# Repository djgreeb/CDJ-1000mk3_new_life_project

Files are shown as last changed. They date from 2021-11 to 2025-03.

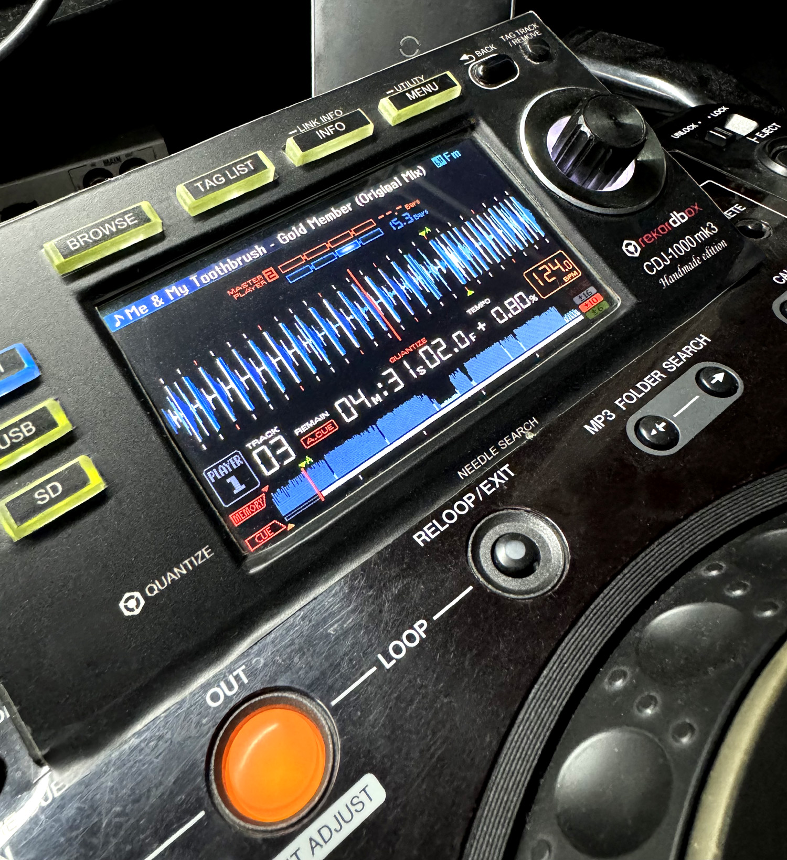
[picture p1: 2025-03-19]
v.1.17.JPG

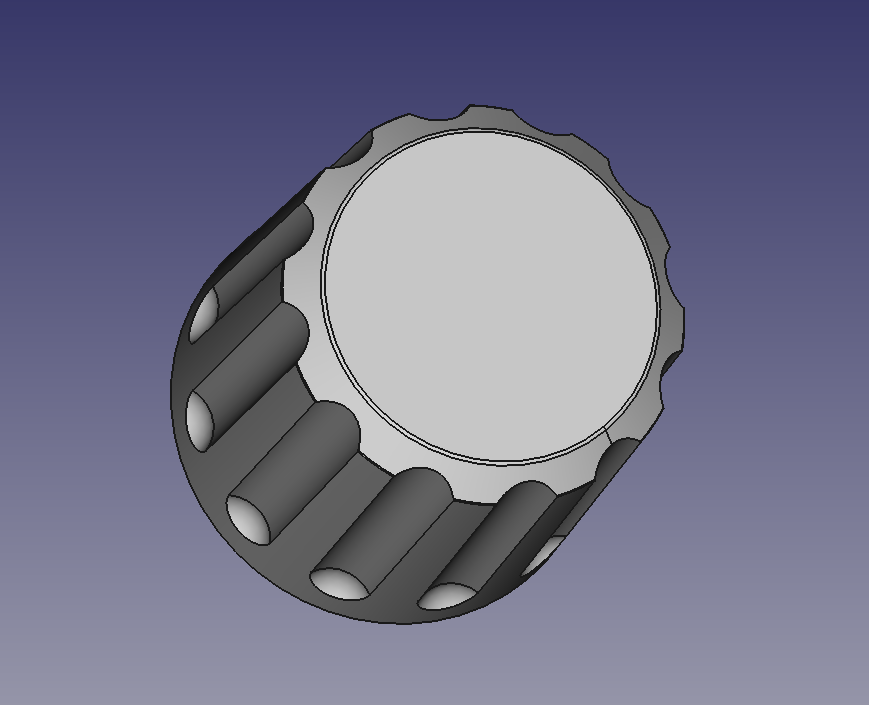
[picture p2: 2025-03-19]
Encoder knob 3D/Knob view.png

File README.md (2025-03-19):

# CDJ-1000mk3 new life

CDJ-1000mk3 new life - is a project to give new life to the Pioneer CDJ-1000mk3 dj player.

The CDJ-1000mk3 with faulty CD drive or main assy is suitable for the project. It is important that the power supply and control panel boards are in good working order.

The player is connected to the STM32F746G-DISCO board, for which firmware has been created that simulates the CDJ-2000nxs graphical interface, audio playback from micro SD cards, and playback control using the CDJ-1000mk3 control elements.

The current version of the project is developed and tested only for CDJ-1000mk3. Mk1 and MK2 are not supported, although theoretically it is possible, but requires code modification and testing with these players.

Screen with wide version of the waveform (1.17)

v 1 17

Screenshot of previous versions

scrn7

      Version history:
            
	ver. 0.61a
		- optimized browser function
		- added dark_green color in browser for text on white line cursor 
	ver. 0.62a
		- optimized DATABASE_PARSER finction
		- DATABASE_PARSER using WFORMDYNAMIC massive only 
	ver. 0.63a
		- optimized LOAD_TRACK function. Now the PCM[] massive is not used.
		- PCM[] converted in uint16_t
		- optimized audio processing for new uint16_t PCM[]. Now the calculation of 1 sample is 5us instead of 7.5us 
	ver. 0.64a
		- fixed joint in circular buffer in audio processing
		- optimized ring buffer size for increased audio processing performance
	ver. 0.65a
		- optimized audio processing (read SDRAM). Now the calculation of 1 sample is 4us 
	 	- added SD_LED blink
		- added encoder blink when loading track
	ver. 0.66a
		- added touch screen control
	ver. 0.67a
		- added basic function needle search
		- fixed function BSP_LCD_DisplayStringAt. 
		- added TRANSPARENT_MODE for text. 
		- changed method of determination the font with dynamic width (Font15P) and other fonts with static width.  
		- optimized touch controller driver
		- create audioparcer for SEEK function
	ver. 0.68a
		- added QSPI flash support
		- added animation startup logo
	ver. 0.69a
		- added REKORDBOX logo on startup
		- added tag list 
		- added internal function for RedrawWaveforms process 
	ver. 0.70a
		- added INFO mode in BROWSER and TAG LIST menu
		- added internal functions for optimize code
	ver. 0.71a
		- improved the functionality of the TAG LIST menu
	ver. 0.72a
		- added symbol red check mark for TAG LIST
		- improved the functionality of the TAG LIST (added TAG TRACK/REMOVE button)
		- bugs fixes internal functions browser and tag list
		- bugs fixes NAVIGATOR function
		- added loading track from TAG LIST
	ver. 0.73a
		- added UTILITY window
		- added long press MENU button for entering to UTILITY
		- fixed check WAV header
		-	optimized process add/delete tracks in TAG LIST
	ver. 0.74a
		- added SPI transfer for CDJ-1000mk3 panel
	ver. 0.75a
		- added reading cues and memory pionts from ANLZXXXX.DAT
		- fixed bug SPI DMA (see note*) 
	ver. 0.76a
		- added PLAY, TEMPO, TEMPO RESET, JOG MODE buttons
		- added pitch slider 4 ranges
		- added calculation tempo and bpm after pitch change
	ver. 0.77a
		- added PLAY blink led, CUE led
		- improved jog vinyl mode (inertial process)
		- added TRACK SEARCH buttons
		- improved ShowTempo function
		- added TIME MODE button, REMAIN MODE
		- added CDJ JOG MODE work
		- optimized pitch bend coeficients aka CDJ-1000mk3
		- optimized VINYL MODE precision jog step
	ver. 0.78a
		- improved static scroll UI
		- added BEATGRID massive
		- shift up 1px static information, static waveform 
		- beatgrid support
		- improved Phase Meter
	ver. 0.79a
		- improved BPM calculating after pitch change
		- added BPMGRID for tracks with variable BPM 
	ver. 0.80a
		- added Font13D for phase bars
		- added slip mode marker on jog display
		- added master player ICON
		- added slip mode red button and slip mode jog illumination
		- fixed bug spin jog at maximum speed (variable overflow)
		- added first SLIP MODE functions with audio processing
		- added animation icon and gradient for phase bars
		- improved jog pitch bend in reverse mode
		- improved jog in slip mode
	ver. 0.81a
		- added CUE blink
		- improved time mode button code
		- added VINYL RELEASE/START and TOUCH/BREAKE mode 
		- optimized SPI-DMA transfer process
		- optimized potenciometer's curve for VINYL RELEASE/START and TOUCH/BREAKE mode
	ver. 0.82a
		- added track nubmer and status (playing or played) in INFO mode
		- added filling buffer step sequencer for optimize time gaps
		- fixed filling buffer step sequencer algoritm
	ver. 0.83a
		- improved the work of the function of static and dynamic waveforms
		- added "remain/foward time style" for progress bar
	ver. 0.84b
		- added blink progress bar when the remaining time is less than 30sec
		- fixed DrawMinuteMarkers function
		- improved performance static and dynamic waveforms (added ForceDrawVLine function)
		- added checking device UID 
		- fixed fatal error when deleting a track from an empty tag list
		- the first addition of a function CUE audio
	ver. 0.85b
		- added CUE button process
		- improved CUE audio process
		- optimized pitch bend coefficients
		- added loading of Hot Cues and Memory Cues attributes
	ver. 0.86b
		- added MEMORY CUE calling
		- bugs fixes calling CUEs when jog in CDJ mode
		- added CUE, MEMORY CUE and HOT CUE triangles on dynamic waveform
	ver. 0.90b
		- database parser DeviceSQL updated based on document: "Rekordbox Export Structure Analysis" James Elliott Deep Symmetry, LLC
		- change colorystic dynamic waveform (lower white point)
		- change long touch timer for MENU button
		- added bpm to INFO menu
		- added colored rating to INFO menu
		- added KEY to INFO menu
		- added duration to INFO menu
		- maximum tracks in database - 512 (not enough memory)
		- maximum playlists in database - 20 (not enough memory)
		- supported only latin encoding in track names and tags
		- added encoder signal filter
		- show KEY on waveform fisplay
		- added pages in the browser with animation: playlists, tracks, SD card information
		- browser animation bug fixed
		- resized cue marker on dynamic waveform
		- change logic INFO button
		- fixed database parser
		- fixed text line overflow error
		- added REALTIME CUE (set, when track playing) 			
		- added AUTO CUE to the first bit of the bitgrid
		- added full UID chip in HEX in utility			
		- fixed TAG LIST exiting borders when deleting tracks
	ver. 0.97b
		- improved browser menu
		- add flash disk name and date (at the root of the browser)
		- fixed floating pitch tempo values
		- improved slip mode on CUE
		- fixed the work of jog with a hot CUE
		- improved mechanical imitation of jog
		- changed color and style gradient bar
		- changed color dynamic waveform
		- optimized dynamic waveform work
		- added QUANTIZE for CUE and LOOP
		- exclude noise at the end of the track
		- added CRC control for SPI Rx package
		- fixed start phase detection BEATGRID
		- added LOOP MODE (beta)
		- optimized time display function to improve performance	
	ver. 1.03
		- changed function control for SPI Rx package
		- in UTILITY it is now possible to change parameters and save to internal memory
		- added load lock
		- added AUTO CUE LEVEL with MEMORY, FIRST BEAT MODE and analog tresholds (-36dB, -42dB and other)
		- added TIME MODE DEFAULT 
		- added TEMPO RANGE DEFAULT 
		- SLIP REVERSE MODE for REVERSE SWITCH
		- added ability to select RGB or BLUE waveforms
		- added LCD brightness
		- added jog indicator when the track ends 
		- added jog brightness
		- added BPM color
		- added audio output level
		- for use JOG PWM output pin CN4-7 for it to work. see schematic STM32F746 Discovery
		- for LCD PWM to work, remove R85 and install 
			it between U10-7 and GND. Remove R81 and R66. Connect together the U10-7 and RMII_CRS_DV, 
			at the point where R66 was.) see schematic STM32F746 Discovery
	ver. 1.05
		- added dynamic waveform color map from original dump cdj-2000nxs
	ver. 1.07
		- fixed rekordbox parser from parser version 0.39 SLDZ project
	ver. 1.11 
		- SDRAM initialization has been removed, which speeds up loading
		- the code is split into separate files
		- increased delay before starting SPI DMA to start transactions between STM and Pioneer panel mpu
		- modify HAL_SAI_Transmit_IT and SAI_FillFifo and HAL_SAI_IRQHandler function
	ver. 1.13 
		- changed interpolators coefficients (optimal 32x, 4-point, 3rd-order)
	ver. 1.15 
		- optimized audio prc (removed unnecessary variable translation operation before sending to SAI)
		- added variable audio TRIM depending on playback speed
		- added an algorithm for smooth changes in the TRIM variable to prevent clicks in the sound when there is a sudden change
	ver. 1.17
		- the dynamic waveform is now 480px wide and has HOT CUEs lettering

Source code 1.03:

https:drive.google.com/file/d/1VFx4JItAnkkie4v-_Njo-SxVj8lTepl5/view?usp=sharing

https:drive.google.com/open?id=18gmD5JTporbCdqWj66FL6tRKBdp1W8vY

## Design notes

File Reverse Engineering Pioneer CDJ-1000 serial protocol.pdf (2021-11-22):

### Pioneer CDJ-1000mk3 Service Manual:

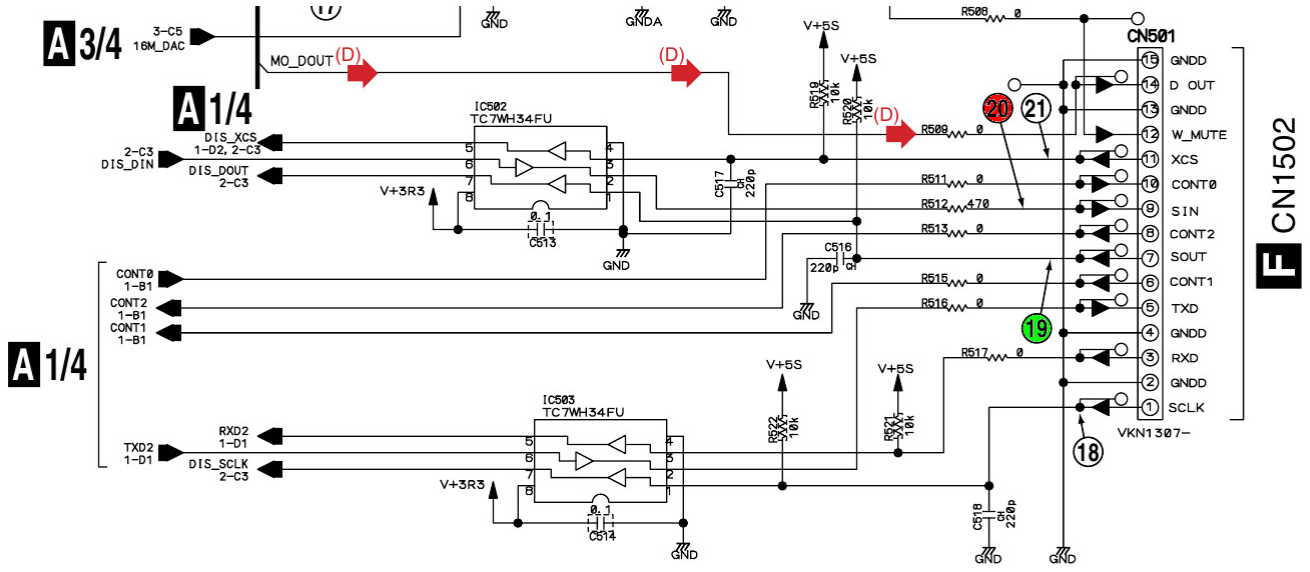
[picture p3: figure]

### 19 - Display Board => Main Assy 20 - : Main Assy => Display Board

### Data: Main Assy => Display Board @ Pioneer CDJ-1000mk3

### Example: MSB b7…..b0 LSB

/ | 0byte | 1byte | 2byte | 3byte | 4byte | 5byte | 6byte | 7byte | 8byte | 9byte | 10byte | 11byte | 12byte | 13byte | 14byte | 15byte | 16byte | 17byte | 18byte | 19byte | 20byte | 21byte | 22byte | 23byte | 24byte | 25byte | 26byte
0 package | 0 | WFM | WFM | WFM | WFM | WFM | WFM | WFM | WFM | WFM | WFM | WFM | WFM | WFM | WFM | WFM | WFM | WFM | WFM | WFM | WFM | WFM | WFM | WFM | WFM | POS | CRC
1 package | 24 | WFM | WFM | WFM | WFM | WFM | WFM | WFM | WFM | WFM | WFM | WFM | WFM | WFM | WFM | WFM | WFM | WFM | WFM | WFM | WFM | WFM | WFM | WFM | WFM | POS | CRC
2 package | 48 | WFM | WFM | WFM | WFM | WFM | WFM | WFM | WFM | WFM | WFM | WFM | WFM | WFM | WFM | WFM | WFM | WFM | WFM | WFM | WFM | WFM | WFM | WFM | WFM | POS | CRC
3 package | 72 | WFM | WFM | WFM | WFM | WFM | WFM | WFM | WFM | WFM | WFM | WFM | WFM | WFM | WFM | WFM | WFM | WFM | WFM | WFM | WFM | WFM | WFM | WFM | WFM | POS | CRC
4 package | 96 | WFM | WFM | WFM | WFM | BAR | BAR | BAR | BAR | BAR | BAR | BAR | BAR | BAR | BAR | BAR | BAR | BAR | 00000000 | BAR | BAR | BAR | BAR | BAR | BAR | POS | CRC
5 package | 120 | BAR | BAR | BAR | BAR | BAR | BAR | BAR | BAR | BAR | BAR | BAR | BAR | BAR | BAR | BAR | BAR | BAR | BAR | BAR | BAR | BAR | 00000000 | 00000000 | 00000000 | POS | CRC
6 package | 144 | ALL | ALL | ALL | AA000000 | ALL | ALL | ALL | ALL | ALL | AA000000 | ALL | ALL | ALL | ALL | ALL | ALL | ALL | ALL | A10001A1 | 00000000 | 00000000 | 00000000 | 00000000 | 00000000 | POS | CRC
7 package | 168 | ALL | ALL | ALL | ALL | ALL | ALL | ALL | ALL | AAA00001 | 1AA10000 | ALL | AA000000 | 00000000 | 00000000 | 00000000 | 00000000 | ALL | 0AAAAAAAAAAAA000 | | ALL | ALL | 00000000 | 0AAAA000 | 00000000 | POS | CRC

[all packages][0 byte] – number of package
[all packages][25 byte] = POS 1…135 – jog display position cursor 138 = eject animation 137 = load in animation 136 = fill circle on display
[all packages][26 byte] – CRC = (1byte + 2byte +…+25byte)%256
BAR - display TIME progress bar (start: [4package][19 byte] end: [5package][8 byte] first bit: b0)
BAR - display CUE progress bar (start: [5package][9 byte] end: [5package][21 byte] first bit: b0)
BAR - display MEMORY progress bar (start: [4package][5 byte] end: [4package][17 byte] first bit: b0) WFM – display WAVEFORM DATA (start: [0package][1 byte] end: [4package][4 byte] first bit: b0)

[6package][1 byte] = xA Track Number (119 = ‘0’ 93 = ‘5’ 18 = ‘1’)
[6package][2 byte] = Ax Track Number or xA Folder Number
[6package][3 byte] = Ax Folder Number (119 = ‘0’ 93 = ‘5’ 18 = ‘1’)

[6package][4 byte][bit6] = ‘FLD’ on display
[6package][4 byte][bit7] = ‘TRACK’ on display

[6package][5 byte] [bit0] = [1] number of track on display table [6package][5 byte] [bit1] = [2] number of track on display table [6package][5 byte] [bit2] = [3] number of track on display table [6package][5 byte] [bit3] = [4] number of track on display table [6package][5 byte] [bit4] = [1] track enable CUE in memory on display table

[6package][5 byte] [bit5] = [2] track enable CUE in memory on display table [6package][5 byte] [bit6] = [3] track enable CUE in memory on display table [6package][5 byte] [bit7] = [4] track enable CUE in memory on display table

[6package][6 byte] [bit0] = [5] number of track on display table [6package][6 byte] [bit1] = [6] number of track on display table [6package][6 byte] [bit2] = [7] number of track on display table [6package][6 byte] [bit3] = [8] number of track on display table [6package][6 byte] [bit4] = [5] track enable CUE in memory on display table [6package][6 byte] [bit5] = [6] track enable CUE in memory on display table [6package][6 byte] [bit6] = [7] track enable CUE in memory on display table [6package][6 byte] [bit7] = [8] track enable CUE in memory on display table

[6package][7 byte] [bit0] = [13] track enable CUE in memory on display table [6package][7 byte] [bit1] = [14] track enable CUE in memory on display table [6package][7 byte] [bit2] = [15] track enable CUE in memory on display table [6package][7 byte] [bit3] = [16] track enable CUE in memory on display table [6package][7 byte] [bit4] = [13] number of track on display table [6package][7 byte] [bit5] = [14] number of track on display table [6package][7 byte] [bit6] = [15] number of track on display table [6package][7 byte] [bit7] = [16] number of track on display table

[6package][8 byte] [bit0] = [9] number of track on display table [6package][8 byte] [bit1] = [10] number of track on display table [6package][8 byte] [bit2] = [11] number of track on display table [6package][8 byte] [bit3] = [12] number of track on display table [6package][8 byte] [bit4] = [9] track enable CUE in memory on display table [6package][8 byte] [bit5] = [10] track enable CUE in memory on display table [6package][8 byte] [bit6] = [11] track enable CUE in memory on display table [6package][8 byte] [bit7] = [12] track enable CUE in memory on display table

[6package][9 byte] [bit0] = [17] track enable CUE in memory on display table [6package][9 byte] [bit1] = [18] track enable CUE in memory on display table [6package][9 byte] [bit2] = [19] track enable CUE in memory on display table [6package][9 byte] [bit3] = [20] track enable CUE in memory on display table [6package][9 byte] [bit4] = [17] number of track on display table [6package][9 byte] [bit5] = [18] number of track on display table [6package][9 byte] [bit6] = [19] number of track on display table [6package][9 byte] [bit7] = [20] number of track on display table

[6package][10 byte] [bit6] =CUE> on display
[6package][10 byte] [bit7] =MEMORY> on display

[6package][11 byte] = xA Time: SEC (119 = ‘0’ 93 = ‘5’ 18 = ‘1’) [6package][12 byte] = Ax Time: SEC (119 = ‘0’ 93 = ‘5’ 18 = ‘1’) [6package][13 byte] = xxA Time: MIN (119 = ‘0’ 93 = ‘5’ 18 = ‘1’)
[6package][14 byte] = xAx Time: MIN (119 = ‘0’ 93 = ‘5’ 18 = ‘1’)
[6package][15 byte] = Axx Time: MIN (119 = ‘0’ 93 = ‘5’ 18 = ‘1’)
[6package][16 byte] = xxA ALL TRACKS (119 = ‘0’ 93 = ‘5’ 18 = ‘1’) when tracks>99 only [6package][17 byte] = xA ALL TRACKS (119 = ‘0’ 93 = ‘5’ 18 = ‘1’)
[6package][18 byte] = Ax ALL TRACKS (119 = ‘0’ 93 = ‘5’ 18 = ‘1’)

[6package][19 byte][bit1] = REMAIN on display
[6package][19 byte][bit7] = A.CUE on display

[7package][1 byte] = xxA tempo (119 = ‘0’ 93 = ‘5’)
[7package][2 byte] = xAx tempo (119 = ‘0’ 93 = ‘5’ 18 = ‘1’) [7package][3 byte] = Axx tempo (119 = ‘0’ 93 = ‘5’ 18 = ‘1’) [7package][4 byte] = xA Time: Frame (119 = ‘0’ 93 = ‘5’ 18 = ‘1’) [7package][5 byte] = Ax Time: Frame (119 = ‘0’ 93 = ‘5’ 18 = ‘1’) [7package][6 byte] = xxA BPM (119 = ‘0’ 93 = ‘5’ 18 = ‘1’) [7package][7 byte] = xAx BPM (119 = ‘0’ 93 = ‘5’ 18 = ‘1’)

[7package][8 byte] = Axx BPM (119 = ‘0’ 93 = ‘5’ 18 = ‘1’)

[7package][9 byte][]
[7package][9 byte]: x11xxxxx (‘+’ on tempo) x10xxxxx (‘-’ on tempo)
x00xxxxx (‘ ’ on tempo)
[7package][9 byte][bit7] = Ax.xx% = ‘1’ of pitch display

[7package][10 byte] [bit5] = xx.x% = ‘.’ dot of pitch display [7package][10 byte] [bit6] = x.xx% = ‘.’ dot of pitch display

[7package][11 byte] | : | 10010000 +-6% on display 10100000 +-10% on display
11000000 | +-16% on display
10000000 | WIDE on display

[7package][12 byte][bit6] = 1 when WIDE Pitch Enable [7package][12 byte][bit7] – MT on display or red diode on button

[7package][17 byte][bit0] = PLAY LED
[7package][17 byte][bit1] = CUE LED
[7package][17 byte][bit2] = LOOP IN LED
[7package][17 byte][bit3] = LOOP OUT LED [7package][17 byte][bit4] = RELOOP EXIT LED [7package][17 byte][bit5] = RED DIODE REVERSE [7package][17 byte][bit6] = RED DIODE HOT CUE A [7package][17 byte][bit7] = GREEN DIODE HOT CUE A

[7package][18 byte][bit0] = ORANGE DIODE HOT CUE A [7package][18 byte][bit1] = RED DIODE HOT CUE B [7package][18 byte][bit2] = GREEN DIODE HOT CUE B [7package][18 byte][bit3] = ORANGE DIODE HOT CUE B [7package][18 byte][bit4] = RED DIODE HOT CUE C [7package][18 byte][bit5] = GREEN DIODE HOT CUE C [7package][18 byte][bit6] = ORANGE DIODE HOT CUE C [7package][18 byte][bit7] = 0

[7package][19 byte][bit3] =MT red diode on button [7package][19 byte][bit4] = tempo reset green diode [7package][19 byte][bit5] = Vinyl blue diode
[7package][19 byte][bit6] = CDJ green diode
[7package][19 byte][bit7] = SD card green diode
[7package][20 byte] | : | 00001000 +-6% on display 00011000 +-10% on display
00111000 | +-16% on display
01111000 | WIDE on display

[7package][21 byte] CPOS 1…85 – jog display position CUE cursor 0 = without cue on jog display

[7package][23 byte][bit3] [bit4] = ”Vinyl ON” on VFD lamp
[7package][23 byte][bit5] = circle “touch enable” on VFD lamp
[7package][23 byte][bit6] = circle “memory empty” on VFD lamp

### 7-segment code:

119 = ‘0’
18 = ‘1’
107 = ‘2’
91 = ‘3’
30 = ‘4’

93 = ‘5’
125 = ‘6’
19 = ‘7’
127 = ‘8’
95= ‘9’

### Data: Display Board => Main Assy @ Pioneer CDJ-1000mk3

/ | 0byte | 1byte | 2byte | 3byte | 4byte | 5byte | 6byte | 7byte | 8byte | 9byte | 10byte | 11byte | 12byte | 13byte | 14byte | 15byte | 16byte | 17byte | 18byte | 19byte | 20byte | 21byte | 22byte | 23byte | 24byte | 25byte | 26byte
0-7 packages | 1 | 16 | ADC T/B | ADC R/S | ADC P | ADC P | ADCT | ADCT | PLS CNT | PLS CNT | JOG SPD | JOG SPD | JOG STS | 00000000 | ALL | 00000000 | ALL | ALL | ALL | CRC | 241 | 100 | 118 | 00000000 | 00000000 | 00000000 | 00000000
[0-7packages][2 byte] = ADC data TOUCH/BRAKE | 0…255 8 bits resolution
[0-7packages][3 byte] = ADC data RELEASE/START | 0…255 8 bits resolution
[0-7packages][4 byte] = ADC Pitch MSB [AAAAAAAA] | 0…16383 14 bits resolution
[0-7packages][5 byte] = ADC Pitch LSB [AAAAAA00]
[0-7packages][6 byte] = ADC Pitch Center Potentiometer MSB [AAAAAAAA] | 0…16383 14 bits resolution
[0-7packages][7 byte] = ADC Pitch Center Potentiometer LSB [AAAAAA00]
[0-7packages][8 byte] = Jog Pulse Counter MSB 0…65535 16 bits resolution (3600 pulses per 1 round) [0-7packages][9 byte] = Jog Pulse Counter LSB
[0-7packages][10 byte] = Jog Speed MSB 0…65535 16 bits resolution (when jog stopped speed = 65535) [0-7packages][11 byte] = Jog Speed LSB

[0-7packages][12 byte][bit0] = Eject Lock switch: 1 = unlock / 0 = lock
[0-7packages][12 byte][bit1] = Direction switch: 1 = forward / 0 = reverse
[0-7packages][12 byte][bit2] = 0
[0-7packages][12 byte][bit3] = 0
[0-7packages][12 byte][bit4] = jog touch enable
[0-7packages][12 byte][bit5] = jog touch enable
[0-7packages][12 byte][bit6] – 1 = jog forward rotation / 0 = jog reverse rotation [0-7packages][12 byte][bit7] = jog rotation detect

[0-7packages][14 byte][bit0] = PLAY button
[0-7packages][14 byte][bit1] = CUE button
[0-7packages][14 byte][bit2] = Loop IN button [0-7packages][14 byte][bit3] = Loop OUT button [0-7packages][14 byte][bit4] = Reloop/Exit button [0-7packages][14 byte][bit5] = Hot Cue A button [0-7packages][14 byte][bit6] = Hot Cue B button [0-7packages][14 byte][bit7] = Hot Cue C button

[0-7packages][16 byte][bit0] = REC MODE [0-7packages][16 byte][bit1] = << Track search [0-7packages][16 byte][bit2] = Track search >> [0-7packages][16 byte][bit3] = << Search [0-7packages][16 byte][bit4] = Search >> [0-7packages][16 byte][bit5] = 0
[0-7packages][16 byte][bit6] = 0
[0-7packages][16 byte][bit7] = 0

[0-7packages][17 byte][bit0] = < MP3 FOLDER SEARCH [0-7packages][17 byte][bit1] = MP3 FOLDER SEARCH > [0-7packages][17 byte][bit2] = JOG MODE button [0-7packages][17 byte][bit3] = TEMPO button [0-7packages][17 byte][bit4] = MASTER TEMPO button [0-7packages][17 byte][bit5] = TEMPO RESET button [0-7packages][17 byte][bit6] = 0
[0-7packages][17 byte][bit7] = 0

[0-7packages][18 byte][bit0] = CALL > [0-7packages][18 byte][bit1] = < CALL

[0-7packages][18 byte][bit2] = MEMORY button [0-7packages][18 byte][bit3] = DELETE
[0-7packages][18 byte][bit4] = EJECT button
[0-7packages][18 byte][bit5] = TIME MODE/AUTO CUE button [0-7packages][18 byte][bit6] = TEXT MODE button [0-7packages][18 byte][bit7] = 0

[0-7packages][19 byte] - CRC

Author: Anatsko Andrei

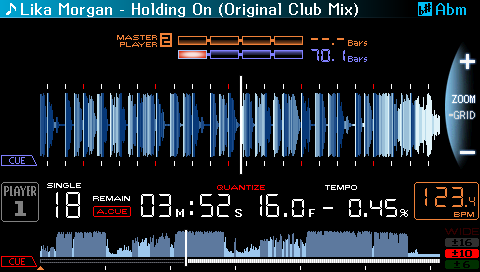
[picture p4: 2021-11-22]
scrn7.bmp

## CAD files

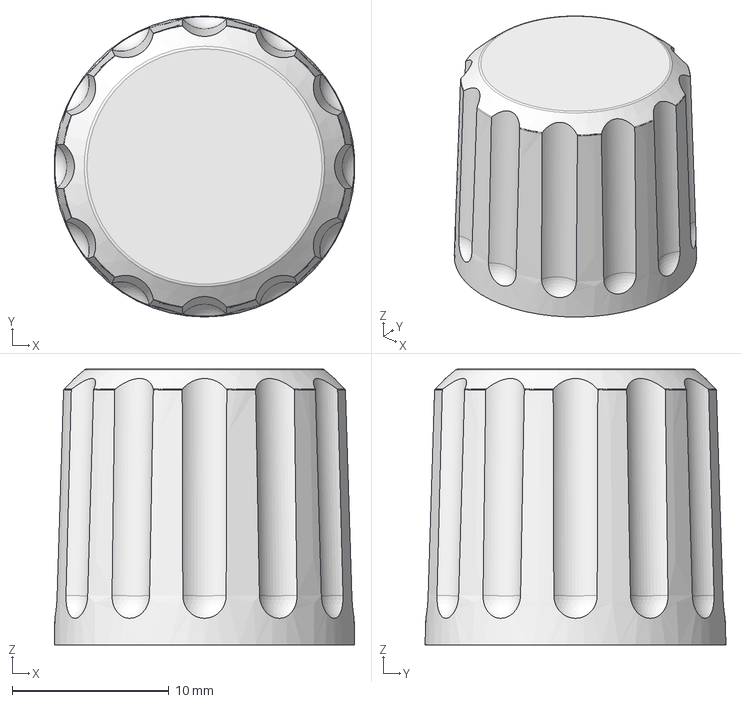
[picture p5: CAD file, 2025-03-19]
Encoder knob 3D/knob_edit24.FCStd
19.2 x 19.2 x 17.6 mm

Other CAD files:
Encoder knob 3D/knob_edit24.stl

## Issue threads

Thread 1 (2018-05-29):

STM32F746 Stuck on loading of logo

ArthurEschner, 2018-05-29:
Followed the install instructions, but the microcontrollers takes forever to load the logo, then it shows the version & progress bar rolls across the display and then it is stuck. It just doesn't do anything after that. Version 85 is the one im referring to. However V86 doesn't even complete loading the logo. Is there anything / settings that I have overlooked in the STUtily app? Any help will be really appreciated.

djgreeb, 2018-05-29:
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

The reason is found. The normal operation of the STM board is prevented by the signals ULPI_1 and ULPI_13. Cut the paths as shown in the picture in my manual (page 12).  I wrote the manual after cutting these paths, so I did not take into consideration that they would interfere with the loading in the new STM boards. Those who first cut the paths, and then downloaded the firmware, did not encounter this problem. Good luck!

ArthurEschner, 2018-05-29:
Totally sorted the issue out. Thank you so much!!

ArthurEschner, 2018-05-31:
Damn, I think I killed my Discovery board!!
It was working perfectly, but after I connected it to the cdj, the screen turned on green (still shows rekordbox though). It's almost like it's missing one layer. Occasionally the screen will display things normally again, but for the most part it's just green. Pc still detects it, but the display seems very dodgy :(  I have ordered another 2 discovery boards & will work on them with extra care next time. If you have any ideas what might be causing my screen issue, I'd appreciate your input. Thanks for your guidance. Regards.

djgreeb, 2018-06-01:
oh, I sympathize with your bad news. Download the demonstration firmware from the STmicroelectronics.com website and flash your STM32F746G board using the STLink utility, check if everything is working on your board (display, touchscreen, audio codec). If you do not find the demonstration firmware, write to me, I will send it to you.
What exactly did you already connect to the CDJ? What signals?
In your CDJ were some kind of defect before that?
Before connecting a new STM32F746G board, check that the CDJ outputs the required voltage (5V and 12V for vled). Did you install the 74HC245 chip? Make sure that this chip receives power from the board STM32F746G (3,3V) not 5V! it is important!

If in CDJ you have already deleted the original display, then it is necessary to apply a 5V 36ohm resistor.

Follow all the steps in the instructions sequentially, after each step, check if you have done everything correctly, only then go to the next step. All connections are made when your board and your CDJ are disconnected from the power.
Sorry, my English is bad, I use a translator.
Good luck to you!

djgreeb, 2018-06-01:
Problems with the green display were always from the very first download or appeared later?
I'll think about this problem. If I have any ideas, I'll let you know.
And further. Write me what's written on your SDRAM chip, it's near the STM32F746G chip

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

ArthurEschner, 2018-06-03:
The problem with the green display appeared later, only after I connected it to the cdj.
It was working perfectly before that. However I don't think the touch screen has ever worked. When I bought the board I never actually tested the demo firmware. I just clicked 'erase' then loaded the Rekordbox firmware. When it was getting stuck on the logo at startup, I decided to load the demo firmware again, thats when I noticed the touchscreen wasn't working. This was before I cut any tracks or modified the board in any way. So I guess it's possible I bought a defective board. Unfortunately I cant return it now because I removed the camera connector & cut the 2 tracks. The SDRAM is 5JL12 (512mb)

djgreeb, 2018-06-04:
It is very strange. Memory, should be installed MT48LC4M32B2B5-6A (128mbit). On my board this is the capacity. In the evening I will check what is written on my chip. If Dicsovery installed 512mbit, it would be very good, I could add more functions (more hot cues, beat-jump), but on the official site there is 128-Mbit SDRAM (64 Mbits accessible) and the same number on my board.

If there is really another SDRAM on your board, this may be the cause of such strange work, you need to study its characteristics.

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

djgreeb, 2018-06-04:
On some boards there is another SDRAM. It is necessary to find out, maybe with your board everything is fine, just another revision.

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

ArthurEschner, 2018-06-04:
That is very interesting.
Perhaps I just read the data sheet incorrectly.
But when I googled the pdf for 5JL12 I was taken to this link: 512Mb: x4,
x8, x16 SDRAM - Micron Technology, Inc.
<https://www.google.com/url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>
I totally agree with you, that looking at the specs written on the
packaging it definitely says 128-Mbit

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

djgreeb, 2018-06-04:
Yes, I saw the same thing in google. I'll look for the marking rules, need to determine exactly which chip is soldered on the board.

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

djgreeb, 2018-06-04:
On my board is installed 5LL12. This is faster  166 MHz, but less capacious SDRAM (128mbit).  5JL12 (512mb) - is slower (100 MHz), and my project works at a frequency of 108 MHz. Perhaps because of this there are problems with the display. The demo firmware works at a frequency of 100 MHz, apparently in order to work on all board revisions. I will lower the frequency in my project to 100 MHz, although I would not like to do this.

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

ArthurEschner, 2018-06-04:
Wow, I wonder if there is any specific stock code to ensure that I get the
correct boards.
I have already ordered another 2, I think I will have a talk with the guys
at ST here in South Africa to see if they are aware that some boards differ.
Do you think the frequency will have a negative impact on performance?
If you can lower the frequency without too much effort as a test, that
would be great. However, it is a lot of work then rather leave it as it is.
I will rather ask the guys at ST to supply me with boards that have a
faster clock speed.
I'm sure a lot of guys are doing your upgrade, so I'm surprised no one else
has had this issue.

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

djgreeb, 2018-06-05:
I will lower the frequency and send you the firmware. I'll do this later, I need a few days for another job. The performance will drop by about 10%, but then this firmware will become universal, for all types of SDRAM.
PS. All this is in theory.  To check whether the SDRAM chip affects the operation of my project, it will be possible only after you download the test firmware.

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

ArthurEschner, 2018-06-06:
Hi Andrei.

Thank you, I really appreciate your help.
Whenever you get the time to do the firmware is fine. It's no problem at
all.
I will test & let you know the outcome.I'm also waiting for a response from
STmicro about the difference in boards.
Perhaps I purchased an old board, but as soon as I know for sure, I will
let you know.

Kind regards Arthur.

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

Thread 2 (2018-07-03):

Source Code

DJDan, 2018-07-03:
I can't seem to find the CDJ1000 mod source code anywhere. There is just the compiled firmware (.hex) file inside the zip.

Could you please put your latest source code on GitHub directly so that others in the community (like myself) can modify/improve the product?

There is options that are coming in future firmware (like USB HID MIDI and USB/.MP3 playback) that people need that could come quicker if others could add to source code too.

Thanks

fer22f, 2018-07-13:
Please consider this, it could start an amazing community effort towards CDJ modding.

The work you have done here is beyond impressing; and you can protect your authorship by using an appropriate license. You can limit commercial use of your software, or make it forcely free using [GPLv3](https://choosealicense.com/licenses/gpl-3.0/) for example, which means everyone using a derivative of your firmware has to disclose the source code and reference your work.

beerjongen, 2018-09-22:
Please make it public, i'm working on a similar project, and I would love to learn from your findings!!

angusmack, 2018-09-22:
I would also like this. I've bought the electronic parts for 2 units and I'm looking forward to getting this working.

I am planning to model the case in 3D and share the STL files once I've done it as a small way of giving back.

I imagine USB support along with other audio formats will be most requested. I hope we will all be able to contribute to this great project.

ecutsa, 2018-09-27:
+1

ecutsa, 2019-01-06:
andrei released the source code

angusmack, 2019-01-07:
Thanks for sharing. Much appreciated.

djgreeb, 2019-01-11:
Good luck!

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

--
Андрей Анацко

Lukasguy, 2020-03-31:
Hi
Would it be possible to update the source code to the new version that was recently released?
I'm currently adding hot cues and loops, and would like to have this on the new version as well.

Many thanks for starting this project, making a good manual and releasing source code! I'm having a great time with this project!

floxia, 2020-04-15:
Anybody has successfully added the loop feature and wants to share the firmware?

vazhnov, 2020-08-08:
@fer22f , please see https://github.com/djgreeb/CDJ-1000mk3_new_life_project/issues/13 for the project license.

Closed 2020-07-26.

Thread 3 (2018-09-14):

Question regarding MK2

geekcroft, 2018-09-14:
Hi there,

Been looking at this with some interest now - I have 2x CDJ 1000 MK2's - do you know whether the modifications would work or are they too different from the MK3's?

djgreeb, 2018-09-17:
cdj-1000 mk2 has differences in the SPI interface, this firmware will not work. I have not studied mk2, but I think there are not great differences. If you are a programmer, have a logic-analyzer and a working mk2, then I think you can do this.

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

--
Андрей Анацко

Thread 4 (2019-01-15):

Problem compiling sorce code

MarceloCampos, 2019-01-15:
Dear Andrei,

First, you did a great job in this project, congratulations.

I´m having problem to compile the code, and think this is because Reset_Handler (reset vector) is missing, attached image of compile result

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

thanks !

angusmack, 2019-01-20:
I'm not sure about this error. I was able to compile and program the source code as it was provided. I loaded the F7.uvprojx project file. Looks like you are doing something different with your project files.

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

Just changed the firmware version as a test of programming:

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

MarceloCampos, 2019-01-25:
thank u angusmack, now is Ok but, the code traps on "demo limit" code size ...

angusmack, 2019-01-27:
I have forked the repo and uploaded the source code https://github.com/angusmack/CDJ-1000mk3_new_life_project

I am in the process of building the electronics hardware. Once I have that I will be able to develop the code. I have had a good look at it and it looks ok to me.

Please, if you want help then raise issues on my fork and I will be able to help better.

Thanks,
Angus

angusmack, 2019-01-27:
I need the hardware so I can make the STM32 work, otherwise it does nothing!!

AIFF and MP3 support are first on my list. Please feel free to request more features on my forked repo.

vincentdallamacchia, 2019-01-28:
hello I would like to know if the loops and hot cues will work with this mod on cdj 1000mk3 and then it would be nice if there was a loop roll section via touchscreen

angusmack, 2019-01-28:
I will work on new features in the software once I have modded my cdj1000mk3 player with the electronics.

This will not happen next week!! Please be patient :)

I have uploaded the source to my repo so other people can work on it if they have the hardware already.

I want to keep this project alive also.

jrsmi9, 2019-01-29:
Hi all, I have basically finished the modification on one cdj, aside from the cdj leds not working (trying to fix that at the moment), and no vincentdallamacchia, currently there are no loops or hot cues in the software from what i can tell.
Unfortunately I have no idea how to write code :(
angusmack, I know it will take a while, but a great feature to include once you are finished would be the ability to sort by playlists from rekordbox, as well as be able to read mp3 tags once that is supported (currently it displays "House" for every song genre).
For the case and buttons, i had them 3D printed and i can email anyone the stl files if you want them

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

vincentdallamacchia, 2019-01-29:
ok angusmack looking impatiently :)) this project has impressed me from the first moment but unfortunately I'm just an electronic expert and not a programmer so I'm waiting for your news ... I've designed some improvements on the type of hardware for the case I'm going to use this coverage original of the cdj 900 the code is dnk5442 fits very well on the display by 4.3 of the st ... and then I'm also using the original keys of the cdj 900 code dac2480 for the keys tagtrack and back then code dac2482 for the device keys and finally dac2492 for the browser keys utility taglist and info ..... comes a very clean job and for the sd card I'm using the slot of the front of the sd card of the same cdj ...... these are all hardware improvements .... .for the software improvements wait for you angus :))) greetings soon I hope :)

vincentdallamacchia, 2019-01-29:
would be nice a performance section on the touchscreen display that would implement auto loops, loop roll and hotcue .... otherwise the software is fine even with wav files that in my opinion are the best sound quality and are analyzed even better by rekordbox having bitrate fixed .... the only flaw is that if you have many tracks of course is a problem of space ...

angusmack, 2019-01-29:
I think USB support would be good too. Connect micro USB cable from STM to female USB standard socket exposed on case so you can use a USB stick as well as SD card.

I use AIFF so support for that format as well as WAV (very similar) would be nice :)

I just need to make the PCB for the buttons and encoder wheel so I can interact with the STM first...

vincentdallamacchia, 2019-01-29:
ok wait for updates :)))

angusmack, 2019-01-29:
@jrsmi9 - please can you push the STL files for the case and buttons to my repo https://github.com/angusmack/CDJ-1000mk3_new_life_project in a new folder called "STL Files". If you don't know how to do this then you can email them to me angus dot mack at gmail dot com and I will do it. Thanks.

vincentdallamacchia, 2019-01-29:
however I doubt that you can read mp3 with this card stm ... as a format read only the wav
it would take an mp3 decoder

vincentdallamacchia, 2019-01-29:
angus a question using a mini usb to usb female adapter can you already read the usb sticks or still not able ??? then I saw that the buttons work even without the resistors and the capacitors only by connecting them to the ground and instead of the stm of competence except the encoder that needs the resistors of the signal antidebunge

jrsmi9, 2019-01-30:
I've emailed them, check spam folder too perhaps

angusmack, 2019-02-06:
Thanks. I got them and I have added them to my repo.

vincentdallamacchia, 2019-02-09:
angus i wanted to know is there an easier way to pick up the 4 ulp signals 1 and 13 and camera 15 and 17 from the stm board ??? the tracks are very thin and sometimes you can not weld on them even if you have a magnifying glass :(

jrsmi9, 2019-02-09:
For the ulp 1 and 13  I cant help, I managed to solder them correctly
For the Camera 15 and 17 you can use a ribbon cable breakout board such as this one below which makes it a lot easier:

Breakout Board
https://www.ebay.com/itm/1pcs-30-Pin-0-5mm-FFC-FPC-to-30P-DIP-2-54mm-PCB-Converter-Board-Adapter/252986447855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

Ribbon Cable
https://www.ebay.com/itm/FFC-FPC-Flexible-Flat-Cable-Ribbon-30-Pin-Forward-Reverse-Pitch-0-5mm-1-0mm-/263425258855

jrsmi9, 2019-02-09:
However I am unsure if I have done the camera connections correctly as the LED on my CDJ still do not light up. Angus I am wondering if you can tell from the source code which conections are responsible for signalling the CDJ LED's to turn on, so that I can determine where I have gone wrong?

vincentdallamacchia, 2019-02-10:
thanks I will try to weld the wires ulp 1 and ulp 13 hoping not to do damage and another question there are news about hot cues and loop roll ?? as soon as I finish I will try to post the photos with the original pieces looks like a cdj 900 nexus .... ah another question is possible with this card use a 7-inch screen like that of raspberry also without touchscreen .... I saw of an Italian guy who used raspberry by installing the program directly on the board and can be used with any cdj .... raspberry is much more complete as inputs and many boards of arduino are compatible with it and costs much less than the stm ..... however, rekordbox and its layout are always my favorites:);) ..... I am impatient for the hot cue firmware .... in these days I noticed that loading a track automatically opens the tag list menu and makes a kind of flashing until I hit the browser button or else .... it happened to some of you ??? sorry if I have harassed ahahahah

vincentdallamacchia, 2019-02-10:
sorry this poor english but I use google translate .....

djgreeb, 2019-02-25:
Unfortunately I did not work with Rasoberry, perhaps it would be a better solution than STM. There were no problems with the TAG button. Check the solder wire and button.

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

--
Андрей Анацко

djgreeb, 2019-02-25:
It is not possible to output all signals through a ribbon cable. ulp 1 signal with hardware interrupt, it can not be reassigned to the camera connector

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

--
Андрей Анацко

djgreeb, 2019-02-25:
I was not involved in the implementation of software mp3 decoder. This will be the last step. It all depends on how much free resources remain in the processor.

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

--
Андрей Анацко

djgreeb, 2019-02-25:
The front port on the SD card (CDJ-1000mk3) is too far from the STM, I'm not sure if it will work well at high speeds, there may be problems with interference.

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

--
Андрей Анацко

djgreeb, 2019-02-25:
Congratulations! good job! I posted the source code in public, I hope this will speed up the process of improving the firmware by other users.

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

--
Андрей Анацко

djgreeb, 2019-02-25:
Do you have problems with backlighting buttons on the CDJ or with panel buttons (BROWSE, TAG LIST, INFO ...)? If the problem with the buttons on the CDJ, jog, pitch work? If yes, then check CAMERA_15 -> SIN

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

--
Андрей Анацко

djgreeb, 2019-02-25:
Hi, this is Andrew. I do not have much time to engage in this project, and not a large number of people have an interest in it (I think so). 0.86 is the latest update for the moment, but I posted the source code of the firmware publicly, I hope this will speed up the development

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

--
Андрей Анацко

vincentdallamacchia, 2019-02-26:
pity Andrei because I think you're the only one who could take a project of this .... I took a look at your other projects and I must tell you that if I had your skills I would not leave aside so .... I'm an electronic expert but unfortunately I can not make do with the programming .... so I ask your help and that of angus to carry out this project that excites me .... it would be nice if it worked the loops and hot cues. ... even if you read the wav without mp3 .... great work Andrei

angusmack, 2019-03-01:
Originally I forked the repo so I could work on it but this meant search was not working properly so I have made a copy here https://github.com/angusmack/CDJ-1000Mk3-MCU-Mod

If you require any support or assistance or want to ask questions please do so in this repository so we can all share what we have.

To be clear Vincent: although I am very capable to create the features you are asking for, the time I can dedicate to this project is small and I will do what I can when I can. If anyone else wants to submit pull requests to the repo then please feel free.

I am looking forward to making this work so please Star/Follow the repo and share.

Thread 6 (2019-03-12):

Mini-PCB

maatje68, 2019-03-12:
Hello,
On page 11 you showed a mini-pcb.
I can't find any draw and equipment list for it.
What do i need and how can i get it?

Regards, Marcel

djgreeb, 2019-03-16:
Hi, this board is in the table on page 3
"TSSOP to DIP adapter board (if you have a circuit in another package, then you need an
adapter for your circuit type package) 1pcs
Can be bought here:
https://www.ebay.com/itm/5pcs-SOP-SSOP-TSSOP-SOIC24-to-DIP-Adapter-PCB-Board-
Converter-Double-Sides-
F06/171216713832?epid=752562730&hash=item27dd4fb868:g:iLIAAOxyUrZS1Blh
or other online stores or radio market."

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

--
Андрей Анацко

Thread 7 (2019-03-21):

Digital audio noise in end track

fabiodj2, 2019-03-21:
Hello everyone ... I've done my design step and it's almost all working ...

I am printing the case for the STM board and very eager to get everything ready. I was testing all the functions and I noticed a big one, I believe that it could be some problem in my STM, so I would like you to do a test in the same way that I like in the video below:

https://youtu.be/iJTq9NwelFo

The problem is a digital noise whenever the Tracker is finished and the CDJ Pitch is out of 00.00%.

Has anyone else had this problem?

Thank you Very much!!!

djgreeb, 2019-03-31:
Hey. I understand what it is about. This noise is heard because the last audio frame continues to play. This is not an error, I just have not added the firmware yet and have not closed this bug.

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

--
Андрей Анацко

fabiodj2, 2019-03-31:
Hi...thank you very much for your feedback...do you have any forecast when we will have a new firmware with new functions? I've made some changes to the case design and I'm going to do a few more things in the electronics. As soon as I finish I can share the changes and ideas with you! Of course if it is your wish! On the case of colored Waveformes, would colored candles be possible?

fabiodj2, 2019-03-31:
Hi...thank you very much for your feedback...do you have any forecast when we will have a new firmware with new functions? I've made some changes to the case design and I'm going to do a few more things in the electronics. As soon as I finish I can share the changes and ideas with you! Of course if it is your wish! On the case of colored Waveformes, would colored candles be possible?

djgreeb, 2019-04-14:
Hi. I can not name the timing. Last time I was not involved in this project.

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

--
Андрей Анацко

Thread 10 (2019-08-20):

Only 32F746GDISCOVERY

jdkid86, 2019-08-20:
Hi Andrei,

Thanks for this project. I am very interested in buying this board and researching.
Do you think you could use your Firmware to get playback, pitch, cue from SD card without CDj?
I would create the necessary buttons and faders myself, but I would like to know if this board supports orders in an analog way.

Cheers

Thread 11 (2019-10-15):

next update ?

bdomi60, 2019-10-15:
Hello,
Will an update be planned to add new features such as :
- Hot cues
- Dual deck
- Master tempo
- USB port active

Thanks.

vincentdallamacchia, 2019-11-04:
ciao bdomi60 è una domanda la tua o un affermazzazione ??? grazie se è una domanda è da circa un anno che nessuno si fa più sentire su questo progetto ed è una cosa brutta da dire perchè il progetto merita più attenzione è un bel progetto peccato che Andrei lo abbia abbandonato forse perchè ha poco tempo...credo che solo lui potrebbe fare tutto ciò anche perchè è arrivato a questo punto ....speriamo tutti in un nuovo firmware con hotcue ...loop con loop roll e porta usb ...per quanto riguarda il master tempo non può essere realizzato perchè la scheda non lo supporta...

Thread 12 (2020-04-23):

cdj 1000 mk3 firmware mod to play wav/aiff/mp3

janhase88, 2020-04-23:
hi,
i just found this project on youtube - really great project!
I wonder, is it possible to just mod the firmware (no hardware changes/physical modding) so the mk3 can play wav/aiff & mp3 from sdcard ?

*sry this is probably the wrong place to ask, but i couldnt find your email :-)

cheers

sashabeep, 2020-05-02:
@janhase88 IMO, board power is too weak to handle decoding and all of the interface things at the same time with stable result.

@djgreeb correct me if i wrong. Have you been tried helix decoder?

djgreeb, 2020-05-14:
Hi, maybe the resources of the original processor in the CDJ-1000 are enough to play wav and mp3, but to change the firmware, you need to get the source codes for this firmware, and this is pioneer's personal information.

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
 
 
--
Андрей Анацко

Closed 2020-07-10.

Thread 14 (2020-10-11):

Gerber file issues with PCB.

Xenocrates90, 2020-10-11:
Could I request a new gerberfile generated for the PCB? I'm trying to have PCBs made on jlcpcb.com and It is failing since it cannot identify the Silkscreen layer as well as the board outline.

Thanks in advance, you're really doing good work!

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

mtoonk, 2024-09-22:
I also try to order and get the following message:

1.Hi Sir/ Madam, There are no drill in your file, please kindly check!You can click ‘Replace file’ button to re-upload the file in your JLCPCB account page .Thanks

2.Hi Sir/ Madam, There is no top solder mask in your file, please kindly check!You can click ‘Replace file’ button to re-upload the file in your JLCPCB account page .Thanks

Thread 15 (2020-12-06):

Kicad files

fabiodj2, 2020-12-06:
Hi DJ Greeb,

Would it be possible to send Kicad files for the project's electronic circuit?

Best Regards,

Fábio Lisboa

djgreeb, 2020-12-07:
kicad projects
 

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
 
 
--
Андрей Анацко
 

djludo62, 2022-04-02:
please fille thanks you

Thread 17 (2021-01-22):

Error 15

wussuphaters, 2021-01-22:
Hi ! Thanks a lot first of all, I gave this project a try and managed to do it. I even designed a custom PCB for the buttons etc, making it more convenient. Only problem is, when I load a track, it says error 15 and waveform does not appear. I can still see that SPI is indeed working because i can change tempo etc, but cannot play the track. I used .mp3 converted into .wav, I suspect it is a format error, can you detail this ?

antonio-mx, 2021-01-31:
You're right, the same thing happened to me and it was because of the audio format, it only supports 44.1k 16bit stereo

DJJuciel, 2021-02-02:
hello wussuphaters, how are you? I hope everything is alright!
sorry my english, because i'm using google translator!
I'm starting my project, but on the electronics I'm still an amateur!
Did you mount the SPI LEVEL SHIFTER card? and the custom PCB for the buttons you mentioned?
Would you be able to send me, or the file or photos of how you made these PCBs, will be of great help to me! if you can send me, this is my email: deejayjuciel@gmail.com
Thanks in advance!

wussuphaters, 2021-02-03:
Indeed it was due to a format error ! It is a pretty quick fix using Audacity to convert a bunch of .mp3 files to .wav and then resample them before exporting.

@DJJuciel below you will find a link to the PCB files, you can use JLCPCB or PCBWay to make them, I used JLCPCB and it cost me about 12€ for 5 of them. The PCB is basically a hub for all the components, there are 4 pin headers that are labeled DISCO (connection to Discovery board), CDJ (SPI connexion to CDJ), BUTTONS (button outputs to Discovery board) and LEDS (inputs for LED switching). Individual pinout are not labeled but you can use the .sch files (Eagle or Kicad software) to identify them.

Also make sure to order the right component footprints, for example the bus transceiver IC is SOP20 and not TSSOP20, which is smaller.

This PCB is far from being perfect but I hope it can be of use to some who would like to recreate the project ! It has been working fine for me :)

https://drive.google.com/drive/folders/12zg70nERy2KB2MboOX39imnLJUJ70jv0?usp=sharing

Closed 2021-02-03.

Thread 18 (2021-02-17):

SPI level shifter

Stevieheff, 2021-02-17:
Hey guys :) So i have decided to attempt this project. After piecing together all my parts i am struggling with soldering the 74HC254 chip to the breakout board. I am using 0.6mm solder with a fine tip. are there bigger components that i can use instead of the smd chip? I am excited to attempt this project and i would appreciate if you guys had any photos from during your build that i can reference? :)

Letrab, 2022-04-01:
Here is an explanation of a (through hole) SPI level shifter as well, probably compatible? https://www.vandoeselaar.com/tinkering/cdj-1000-mk3-for-rekordbox/

mtoonk, 2024-09-09:
@Stevieheff did you managed to make the level shifter? As a n00b I also find it very complex to make it. Does someone have clear pictures of the boards in relation to the schemes. Maybe someone used a breadboard?

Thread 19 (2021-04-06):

Cue point snaps back

Hylke33, 2021-04-06:
When on a cue point and the jog is used to 'scroll' through the track; the track snaps back to the cue point as soon as the jog is released again rather than staying in the position the track was moved to.

Closed 2021-07-26.

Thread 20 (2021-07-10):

test music playback without browse buttons

mdethmers, 2021-07-10:
hey, first of all, this project is amazing! love the idea of upcycling such a product!

I have bought everything needed for the mod, and have it all connected now. the buttons all seem to work (bpm, quantize, time etc.) but I have no idea how to load a track on it!

i just have the screen connected, and loaded with a 44.1khz 16bit wav file, but pressing the search track or search button does not appear to be doing anything! also no errors on the screen etc... the self assembly guide says that you should be able to use the track search to load tracks, butit does not seem to work? I don't think its a connection error as the rest works fine. any thoughts on this?

thanks!

fabiodj2, 2021-07-12:
Hello friend....I'm glad you also decided to do this project...could you
send me a video of what's going on? It would be easier to tell you

Em sáb., 10 de jul. de 2021 13:57, mdethmers ***@***.***>
escreveu:

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

mdethmers, 2021-07-12:
hey fabio, thanks for coming back to me and willing to help me out!

I've made a video for you which shows what works/does not work.

https://www.youtube.com/watch?v=oDTlho7wmc0

the sd is loaded with a 44.1khz 16bit sample song as well! is there maybe another version from which I could try to load the song?

fabiodj2, 2021-07-13:
OK my friend...now I understand....You will need the encoder to load and
browse the songs and also the project browser buttons.

[image: image.png]

https://www.ebay.com/itm/Brand-New-Rotary-Encoder-EC11-Digital-Potentiometer-Handle-15mm-20mm-Kit-Set/222355519139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

https://www.ebay.com/itm/100pcs-3X6X2-5mm-Tactile-Push-Button-Switch-Tact-Switch-Micro-Switch-2Pin-SMD-S2/261995936109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

The CDJ project uses in a mixed way the original keys from the panel of the
CDJ-1000 MK3 and also the keys "created" by the author of the project.

If you have difficulty with the electronics part and want a plug and play
item from the project...I've finished here the cases, buttons, keys and
other items.

[image: image.png]

Instagram...

https://www.instagram.com/explore/tags/cdj1000nexus/

https://www.instagram.com/p/CM-pbR3FhfP/

Best Regards,

Fabio Lisboa

Em seg., 12 de jul. de 2021 às 13:16, mdethmers ***@***.***>
escreveu:

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

adi2870, 2025-01-04:
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

Hello, mdethmers, I also started this project, very interesting, but my cdj1000mk3 does not start.
Start the board with stm32f, I can select the song from the buttons, but the player does not start.
Do you have any idea, I see that your CDJ is starting.
Thank you!

mdethmers, 2025-01-07:
Hey! I am not sure, but in the end all th functions of the player only worked after I added/connected all the peripheral buttons and sliders. make sure everything is connected and functioning, as the play-button might not be connected now and therefore does not work.

adi2870, 2025-01-07:
Thank you!

adi2870, 2025-01-07:
Thank you!

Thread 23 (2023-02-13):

Error 2,3 or 4

djdoubleg, 2023-02-13:
When i load the track show this 3 error in last line in red.
I try to export with latest 6.6.4 and try with 5.01 samer error.
I only have F746 board, notconnected to CDJ1000 board with SPI.
Maybe there is the problem?

adi2870, 2025-01-04:
Hello, you can only put wav files on the sd card.
Success!

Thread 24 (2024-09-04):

Tag list

mtoonk, 2024-09-04:
Still getting the tag list as start screen After cutting the paths on the disco board.

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

adi2870, 2025-01-04:
Hello, it is necessary to build the board with buttons from the original project, otherwise you cannot see the playlist.
You can only put wav format files on sd.
Success!

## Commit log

2020-01-23 Add files via upload
    // ver. 0.90b
    // - database parser DeviceSQL updated based on document: "Rekordbox Export Structure Analysis" James Elliott Deep Symmetry, LLC
    // - change colorystic dynamic waveform (lower white point)
    // - change long touch timer for MENU button
    // - added bpm to INFO menu
    // - added colored rating to INFO menu
    // - added KEY to INFO menu
    // - added duration to INFO menu
    // - maximum tracks in database - 512 (not enough memory)
    // - maximum playlists in database - 20 (not enough memory)
    // - supported only latin encoding in track names and tags
    // - added encoder signal filter
    // - show KEY on waveform fisplay
    // - added pages in the browser w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
2020-04-16 Add files via upload
    // ver. 0.97b
    // - improved browser menu
    // - add flash disk name and date (at the root of the browser)
    // - fixed floating pitch tempo values
    // - improved slip mode on CUE
    // - fixed the work of jog with a hot CUE
    // - improved mechanical imitation of jog
    // - changed color and style gradient bar
    // - changed color dynamic waveform
    // - optimized dynamic waveform work
    // - added QUANTIZE for CUE and LOOP
    // - exclude noise at the end of the track
    // - added CRC control for SPI Rx package
    // - fixed start phase detection BEATGRID
    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
2025-03-18 Create CDJ1000VER117.hex
    added dynamic waveform color map from original dump cdj-2000nxs
    // ver. 1.07
    // - fixed rekordbox parser from parser version 0.39 SLDZ project
    // ver. 1.11
    // - SDRAM initialization has been removed, which speeds up loading
    // - the code is split into separate files
    // - increased delay before starting SPI DMA to start transactions between STM and Pioneer panel mpu
    // - modify HAL_SAI_Transmit_IT and SAI_FillFifo and HAL_SAI_IRQHandler function
    // ver. 1.13
    // - changed interpolators coefficients (optimal 32x, 4-point, 3rd-order)
    // ver. 1.15
    // - optimized audio prc (removed unnecessary variable translation operation before sending to SAI)
    // - added variabl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
2025-03-19 3D print
    [knob_edit24.FCStd, knob_edit24.stl]
